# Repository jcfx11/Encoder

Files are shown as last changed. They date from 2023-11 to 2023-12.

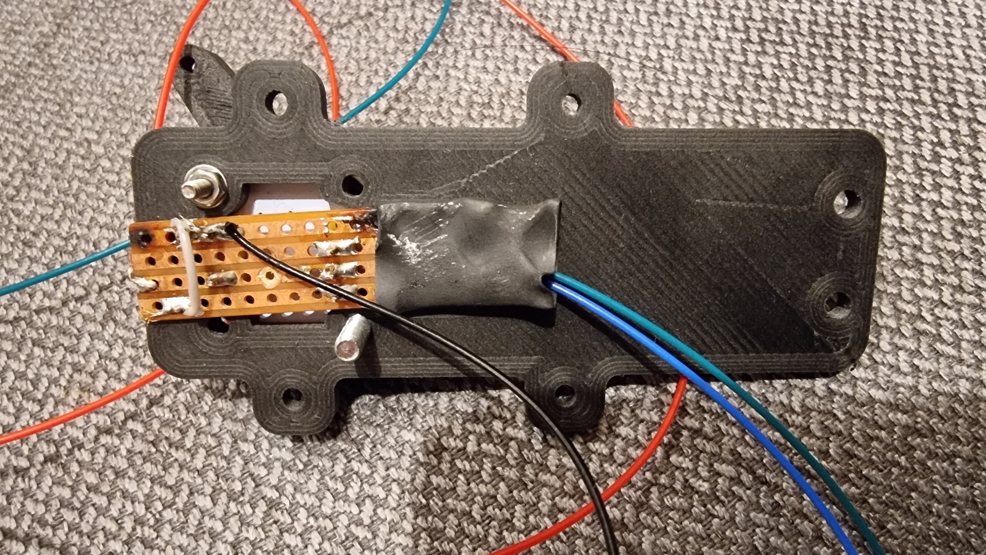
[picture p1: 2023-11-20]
Veroboard sensor wiring.jpg

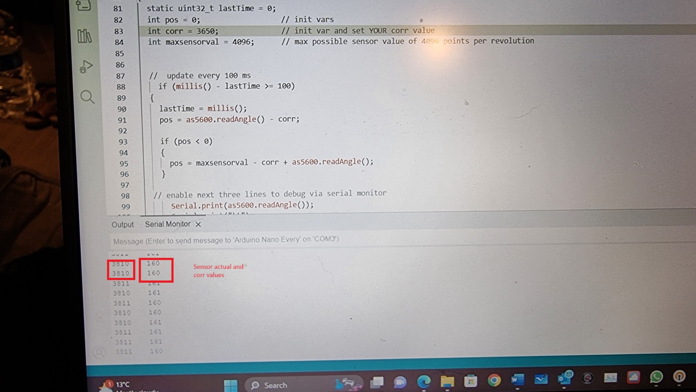
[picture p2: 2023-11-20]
use of calibrate sketch.jpg

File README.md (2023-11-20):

A very simple use of an AS5600 absolute encoder to read an angle and translate that angle to a flap setting displayed on a small oled display. Builds on the work of Scott and Rob Tillart.
Due to the simplicity of the project, ie, no added pusbuttons to set or increment positions, the code is very simple, but does require some ability to change the code where specified to suit your particular installation. I'm using Arduino IDE v2.x

Hardware - Arduino Uno or Nano Every. This code has been tested on both and works. The solution could be ported to any microprocessor that has an I2C bus and provides 3.3V and 5V for the sensor and Oled displays.

AS5600 3.3V absolute encoder, 1.3 inch 5V Mono OLED display from Ebay or similar, 3d printed parts, piece of veroboard, and a "shield" for your microprocessor to enable easy board connections.

Many examples of AS5600 and Oled on Youtube

Needs hands on coding to calibrate and tailor the angles read to the display

The two sensor arms are examples, I expect you will need to tailor the length, for example, to suit your particular installation.
https://www.tinkercad.com/things/aveWrb0Cxmn-flap-sensor-lever

V 1 is complete, ideally V2 will use interupt handling to read the sensor rather than the timer in use now.

Demo of finished article - https://www.youtube.com/shorts/X8wPW7MDXF8

Please excuse my wonky soldering and photos, I'm on holiday.

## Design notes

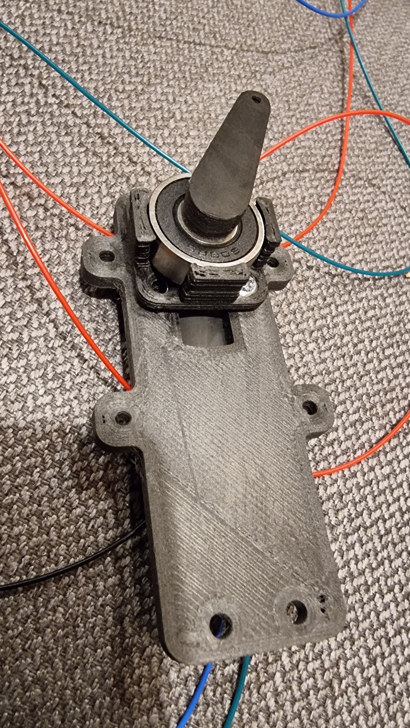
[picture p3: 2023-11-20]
Completed sensor example.jpg

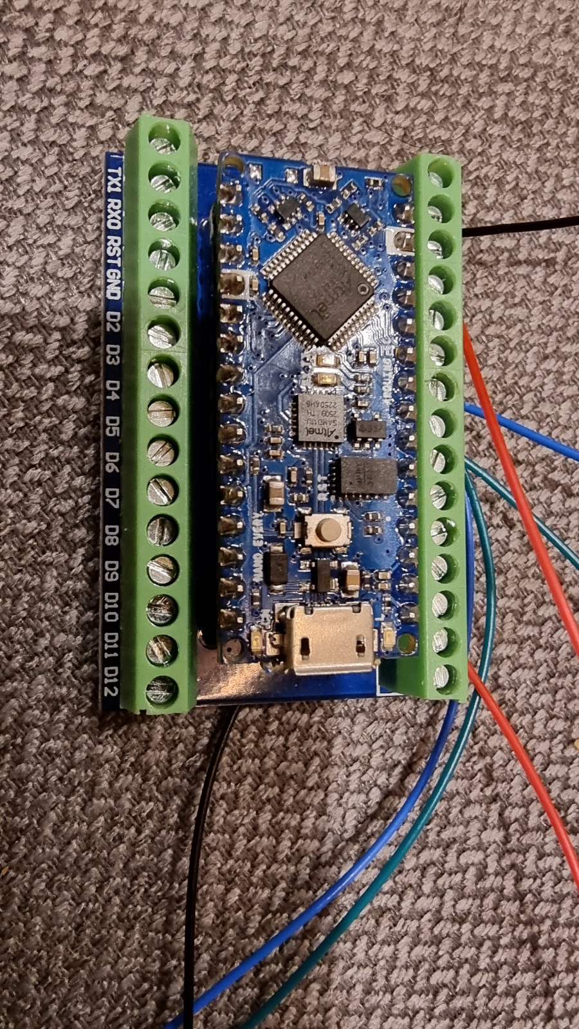
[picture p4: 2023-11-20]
Nano in sheild board.jpg

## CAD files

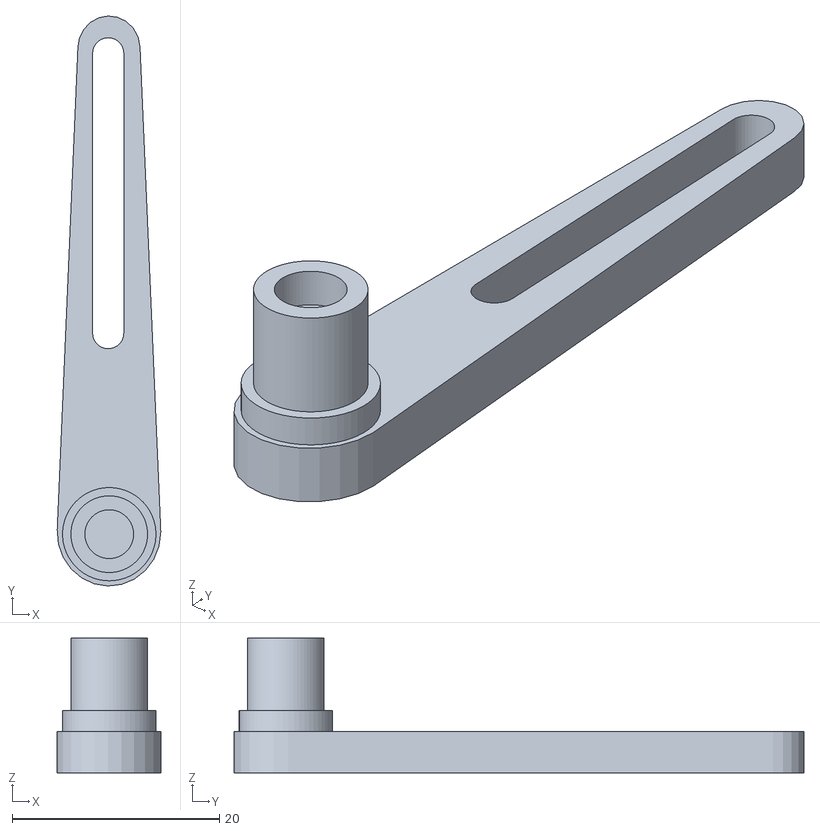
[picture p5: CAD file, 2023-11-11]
Flap sensor arm with slot - Final.stl
9.99 x 55.0 x 13.0

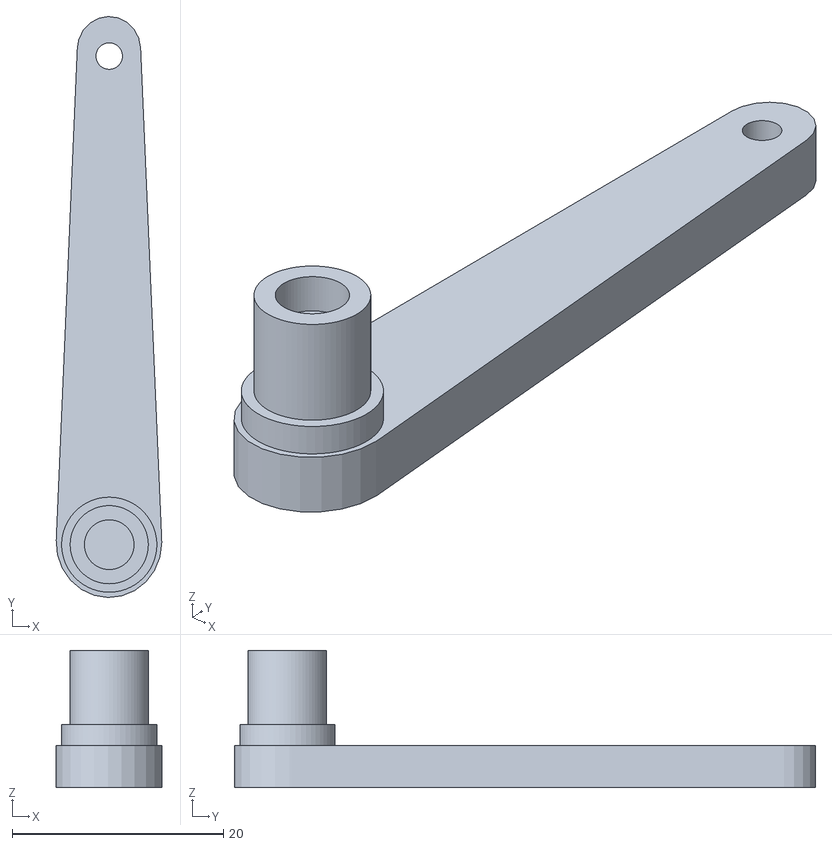
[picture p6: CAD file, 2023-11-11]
Flap sensor arm with hole - Final.stl
9.99 x 55.0 x 13.0

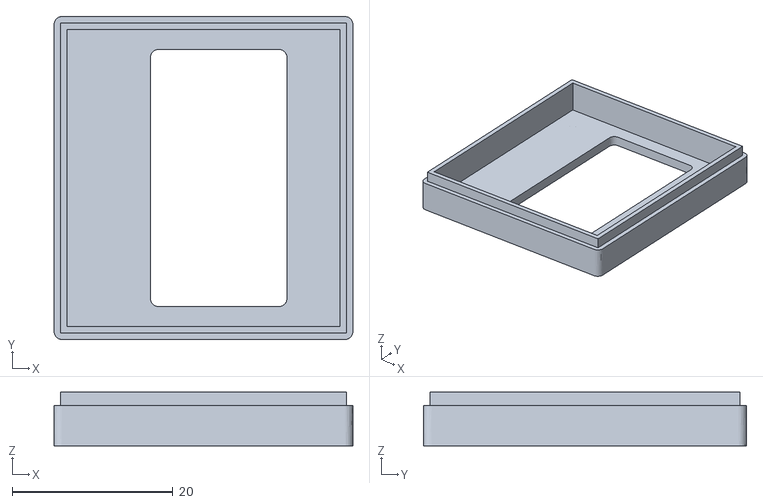
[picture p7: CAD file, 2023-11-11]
1.3 oled case front - Final.stl
37.2 x 40.2 x 6.70

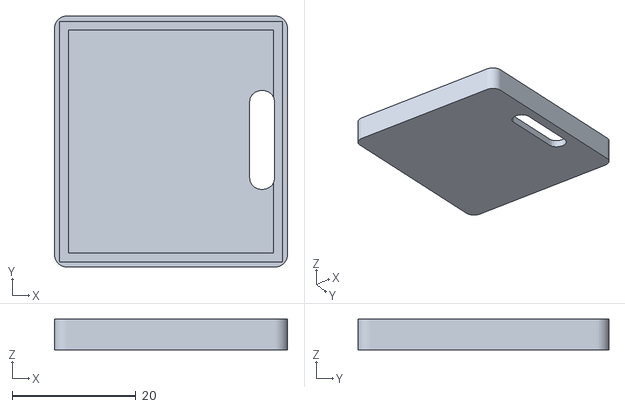
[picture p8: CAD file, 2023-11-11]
1.3 oled case rear - Final.stl
37.6 x 40.5 x 5.00

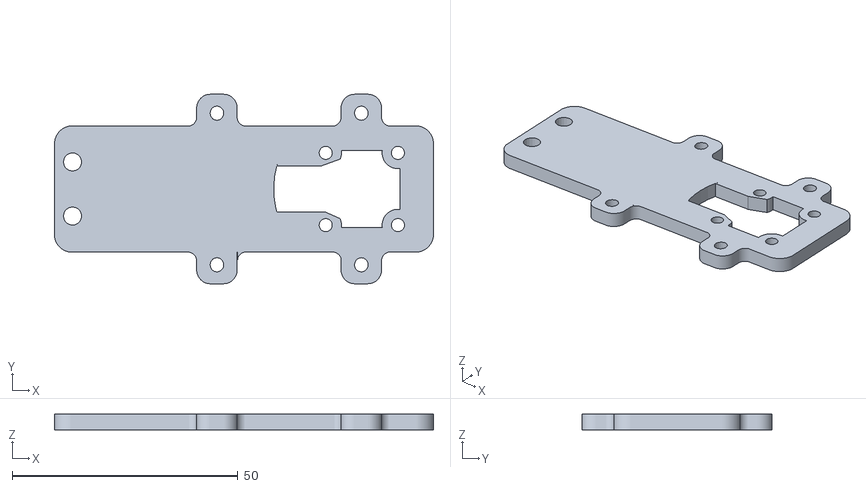
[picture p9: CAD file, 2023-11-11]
Flap sensor mount plate - Final.stl
84.0 x 42.0 x 3.50

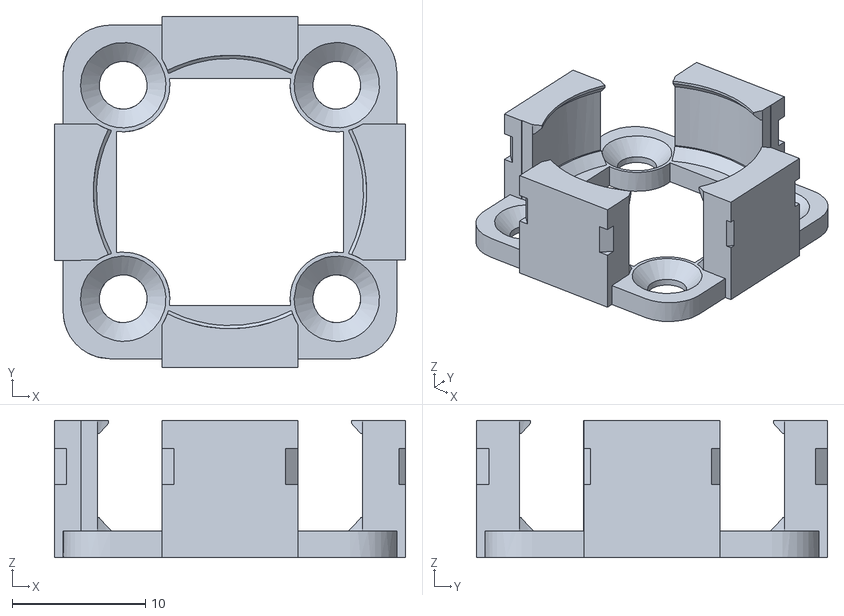
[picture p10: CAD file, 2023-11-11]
AS5600 and 608 bearing mount - Final.stl
26.3 x 26.3 x 10.3

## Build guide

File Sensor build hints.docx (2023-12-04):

# Build hints

Firstly, note that the components are frangible, any resistance should be overcome with a slightly increased force. Do not over engineer a really strong solution !

Acquire the various hardware components, example sources given at end of doc

Print the components and make sure they fit, your printer may have a different tolerance to mine.

Print at 0.1 or 0.15 mm layer height, use 3 or 4 walls, use 20% or 25% infill. Adjust settings as appropriate. Use something with a higher heat resistance than PLA if you live in a warm country

Display case and Oled display – use hot glue or double sided sticky foam pad to hold the Oled to the front case. Use some medium viscosity superglue to join the case halves

Use a tie wrap around the bearing holder to fix the bearing in place

Use a viscous superglue to mount the magnet to the flap arm

Soldering – you can solder directly to the Oled and AS5600 pins. Or you can use some Veroboard to make life easier, or you can make up some 2.54mm Pitch 4 Pin JST SM Connector Dupont Female Pin Headers

Don’t solder directly to the Nano, get a screw terminal shield device to make life easier..

The sensor (AS5600) should rotate clockwise going from Land flap to Speed flap, ie, the sensor value increases as the arm rotates.

Use 4 core shielded cabling, very little current is transmitted.

Keep the Nano behind the panel for ease of access and programming

Add split ferrite cores to cabling in and out of the Nano

Pick a 3d print case for the Nano from Tinkercad or Thingiverse to suit your needs

Read these installation examples here (https://gliding.lxnav.com/wp-content/uploads/manuals/lxFlapsManualEnglishVer0150rev10.pdf) pick a method suitable for your own installation

# Order of build/install

- Print parts
- Build sensor board, bearing mount and arm
- Decide cable routing in order to avoid any control runs
- Test sensor on bench with calibrate.ino, see values alter in the Arduino IDE serial monitor pane
- Install sensor board into glider, do NOT connect the sensor arm directly to the flap handle, always attach to the drive pushrod of the flap cone/bucket
- Run Calibrate, decide if corr value is needed. CORR only necessary IF the readangle passes through zero as flaps move from Land to Speed
- Use table to record your flap POS values
- Calculate the minus and plus fudge factor
- Add values – corr and plus/minus to the Flaps.ino
- Compile and send to your nano
- Attach the display if not already done and test that Flap position display matches reality, if not debug your corr and plus/minus numbers

# Power the board

If you have a good low noise USB power in the panel then use that, otherwise use the 12v glider battery. The Nano will stepdown and still provide 3.3 and 5v.

Don’t power with any more than 12v as the Nano will need to dissipate more heat

# Microprocessor type

Uno should work, all testing done on Nano Every

Any micro that is supported by Arduino IDE and has 3.3v, 5v and an I2C interface should be a viable target

# Display

The Oled 128x64 is the target of this design and all of the case components, however a 128x32 display can be used provided it has I2C capability. In reality any display type could be used but stick to I2C interfaces. The I2C interface is very easy to wire up and to program.

# Components

Oled (https://www.amazon.co.uk/dp/B074N9VLZX?ref=ppx_yo2ov_dt_b_product_details&th=1)

AS5600 (https://www.amazon.co.uk/dp/B09GLPV6WB?psc=1&ref=ppx_yo2ov_dt_b_product_details)

Nano shield (https://www.ebay.co.uk/itm/155756136480?var=456134906693)

Nano every with headers (https://cpc.farnell.com/arduino/abx00033/nano-every-w-header-development/dp/SC18536?st=nano%20every)

Arduino IDE (https://docs.arduino.cc/software/ide-v2)

Radio control pushrods could be used to connect (https://www.nexusmodels.co.uk/aircraft-accessories/model-hardware/linkages-push-rods.html)

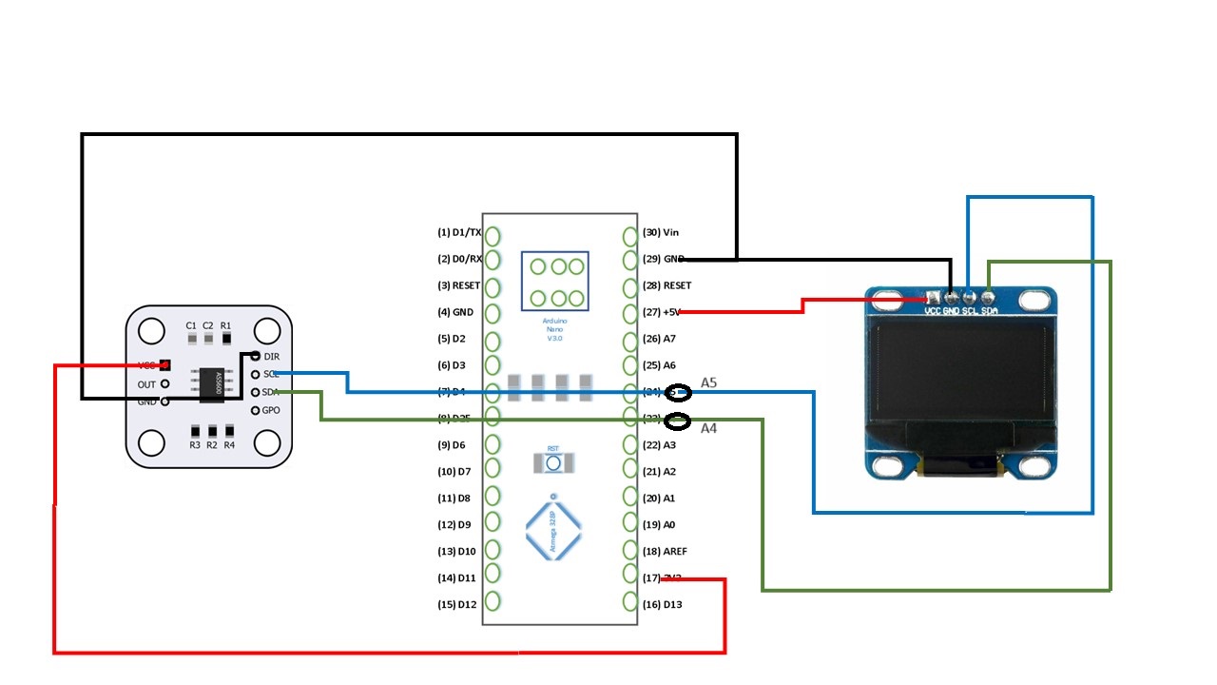
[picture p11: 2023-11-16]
Flaps wiring.jpg

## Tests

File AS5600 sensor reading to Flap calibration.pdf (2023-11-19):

## AS5600 sensor reading to Flap calibration

Having assembled the sensor and installed it in your glider/plane, you will need to record the sensor angular output (0 to 4096) for each of the flap posions you wish to display. The following table is for an ASG29, create a similar table for your installaon.

Lower and upper limits are a fudge factor due to the highly accurate sensor output. The sensor will register 0.1 degree increments, therefore we add a value range to the actual reading to ensure that the flap seng is displayed even when any slack or looseness is present in the installaon.

Having created this table, the values are inserted into the Flaps Arduino code prior to compilaon and upload to the Nano. Refer to the code block example below, this code block is repeated for each flap seng you require.

If the values in the table do NOT wrap round, ie, all values increment and do not cross the 4096 threshold you will not need to use the corr value, set it to zero 0 in the flaps sketch.

If the value does cross the 4096 threshold and wraps round as the example table shows then we will need to use the corr value. Aim for a Land flap value of 100, to calculate the corr value use this;

Corr value = actual reading – 100, which comes to 3650 with a lile rounding. Change the corr value in flaps as shown here

void loop()
{
static uint32_t lastTime = 0; // loop timer
int pos = 0; | // init vars
int corr = 3650; | // init var set corr value
int maxsensorval = 4096; | // max possible sensor value of 4096 points
per revolution

## Actual sensor values as installed – calibrate sketch

Flap posion
Display text

Actual

Land | 3756
Flap 6 | 100
Flap 5 | 400
Flap 4 | 600
Flap 3 | 800
Flap 2 | 900
Flap 1 | 1000

## Re run Calibrate with corr value and calculate the Lower and Upper limits

Flap posion
Display text

Lower limit
Calculated

Pos value aer corr
applied Value

Upper limit
Calculated
Land | 50 | 100 | 150
Flap 6 | 250 | 300 | 350
Flap 5 | 450 | 500 | 550
Flap 4 | 650 | 700 | 750
Flap 3 | 850 | 900 | 950
Flap 2 | 1050 | 1100 | 1150
Flap 1 | 1250 | 1300 | 1350

* Upper limit will not exceed 4096 due to wrapping, sensor reads from 0 to 4096 and then resets to counng from zero. Numbers above are just examples, yours will be different.

Use +- 50 as upper limits and change vales in the code block for each flap seng. +- 50 is an example, yours may need different ranges set.
Code block example

This block shows the settings necessary to show “LAND” on the display

if (pos > 50 && pos < 150) // land flap

{
display.clearDisplay();
display.setTextSize(2);
display.setTextColor(SH110X_WHITE); display.setCursor(0, 50);
display.println("Land"); // Oled text display display.display();

}

## Use of calibrate sketch

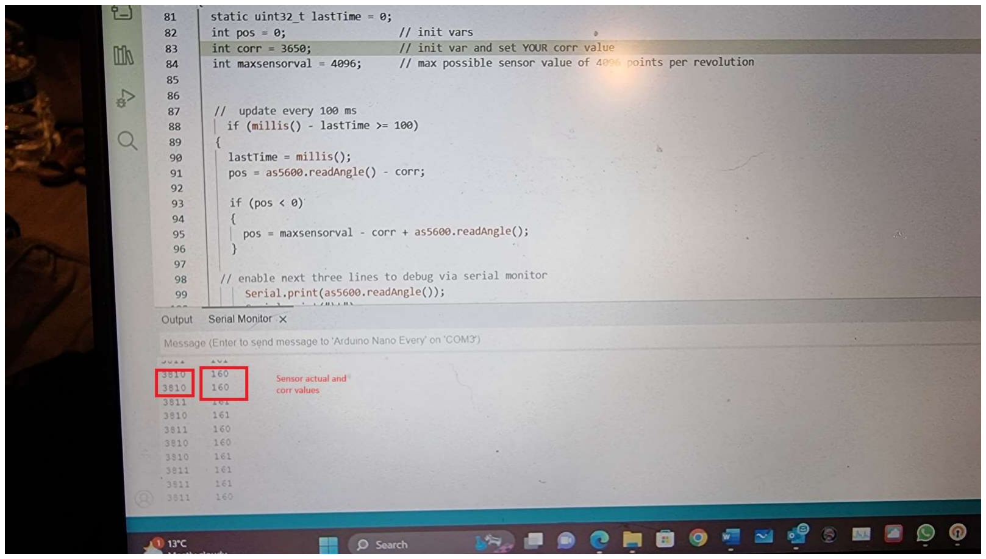
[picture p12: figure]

## Zeroing the AS5600 without use of corr

The sensor will read some random value, ie, not zero when installed. It is very difficult to overcome this BUT it can be done. Please use Rob’s code and instrucons found here

AS5600/examples/AS5600_burn_zpos at master · RobTillaart/AS5600 (github.com)

Note this code is destrucve and can only be run 3 mes on a sensor, use at your own risk !

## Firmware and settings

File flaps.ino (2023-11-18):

//
//    FILE: Flap sensor and display.ino
//  AUTHOR: John Ferguson building on work of Rob Tillaart, x and y
// PURPOSE: Glider flaps encoder sensor and flap position display
//    DATE: 2023-Nov
// AS5600 lib - https://github.com/RobTillaart/AS5600
// Adafruit lib SH110X

/* Parts list

AS5600 encoder          - https://www.amazon.co.uk/dp/B09GLPV6WB?psc=1&ref=ppx_yo2ov_dt_b_product_details
Oled 128x64             - https://www.amazon.co.uk/gp/product/B074N9VLZX/ref=ppx_yo_dt_b_search_asin_title?ie=UTF8&th=1
Bearing                 - generic 608 roller skate bearing, ebay or amazon
3d print parts bearing  - baseplate and bearing mount from tinkercad 
                          https://www.tinkercad.com/things/8eYcTnPwoCL-as5600-and-608-bearing-mount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
                          https://www.tinkercad.com/things/kjFzeW6U8p8-flap-sensor-mount-plate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
Lever arm here          - https://www.tinkercad.com/things/aveWrb0Cxmn-flap-sensor-lever/edit copy and remix for your own purposes
M2.5 nuts and bolts
Veroboard              - ebay or amazon
4 core and shield cable, say 4 m should do

*/

/* AS5600 includes */
#include "AS5600.h"
#include "Wire.h"
AS5600 as5600;   //  use default Wire

/* 128 x 64 Oled includes */

#include <Adafruit_GFX.h>
#include <Adafruit_SH110X.h>
#include <Fonts/FreeSansBold12pt7b.h>

/* Uncomment the initialize the I2C address , uncomment only one, If you get a totally blank screen try the other*/
#define i2c_Address 0x3c //initialize with the I2C addr 0x3C Typically eBay OLED's
//#define i2c_Address 0x3d //initialize with the I2C addr 0x3D Typically Adafruit OLED's

#define SCREEN_WIDTH 128 // OLED display width, in pixels
#define SCREEN_HEIGHT 64 // OLED display height, in pixels
#define OLED_RESET -1   //   QT-PY / XIAO
Adafruit_SH1106G display = Adafruit_SH1106G(SCREEN_WIDTH, SCREEN_HEIGHT, &Wire, OLED_RESET);

/* END of 128 x 64 Oled includes */

void setup()
{
 
  as5600.begin(4);  //  set direction pin.
  as5600.setDirection(AS5600_CLOCK_WISE);  // default, just be explicit.

  delay(250); // wait for the OLED to power up
  display.begin(i2c_Address, true); // Address 0x3C default
 //display.setContrast (0); // dim display, doesn't seem to do anything
 
  display.display();
  delay(250);

  // Clear the buffer.
  display.clearDisplay();
  display.setFont(&FreeSansBold12pt7b); // set your favorite font and size - you will need to alter x and y pos dependent upon font
  //display.setFont(&FreeSans9pt7b);    // other example font
}

void loop()
{
  static uint32_t lastTime = 0; // loop timer
  int pos = 0;                  // init vars
  int corr = 3650;              // init vars
  int maxsensorval = 4096;      // max possible sensor value of 4096 points per revolution

  //  read the sensor value every 100 ms
    if (millis() - lastTime >= 100)
  {
    lastTime = millis();

    // Code block to set the random angle of the encoder to a sensible value for the LAND FLAP position, encode MUST rotate clockwise going from LAND to Speed flaps
    // corr may be left at zero if the "random" position of the sensor reads a sensible low value at LAND FLAP, eg, the range of the sensor must
    // not exceed 4096 and wrap round to zero going from LAND to Speed

    pos = as5600.readAngle() - corr;
    if (pos < 0)
    {
      pos = maxsensorval - corr + as5600.readAngle();
    }

  // clear the display ready for next label
    display.display();
    display.clearDisplay();

    // put the encoder values and labels here - Schleicher in this case - labels are Land, 6, 5, 4, 3, 2, 1
    // Schempp labels are; Land, +2, +1, 0, -1, -2 (best guess)
    // read angle goes 0 to 4096 then resets to 0, cumulative angle keeps incrementing and does not wrap round hence maxsensor val, pos and corr use
    // Example values are embedded below to show how a range of value is set including a small fudge factor to cope with any jitter or vibration in the sensor

    if (pos > 0 && pos  < 200) // land flap
    
    {
        display.clearDisplay();
        display.setTextSize(2);
        display.setTextColor(SH110X_WHITE);
        display.setCursor(0, 50);
        display.println("Land"); // Oled text display
        display.display();
       
    }
 
    if (pos > 200 && pos < 400) // Flap 6
    {
        display.clearDisplay();
        display.setTextSize(2);
        display.setTextColor(SH110X_WHITE);
        display.setCursor(0, 50);
        display.println(" FL 6"); // Oled text display
        display.display();
       
    }
 
    if (pos > 400 && pos < 600) // Flap 5
    {
        display.setTextSize(2);
        display.setTextColor(SH110X_WHITE);
        display.setCursor(0, 50);
        display.println(" FL 5"); // Oled text display
        display.display();
       
    }
 
    if (pos  > 600 && pos < 800) // Flap 4
    {
        display.setTextSize(2);
        display.setTextColor(SH110X_WHITE);
        display.setCursor(0, 50);
        display.println(" FL 4"); // Oled text display
        display.display();
       
    }

    if (pos > 800 && pos < 1000) // Flap 3
    {
        display.setTextSize(2);
        display.setTextColor(SH110X_WHITE);
        display.setCursor(0, 50);
        display.println(" FL 3"); // Oled text display
        display.display();
       
    }

    if (pos > 1000 && pos < 1200) // Flap 2
    {
        display.setTextSize(2);
        display.setTextColor(SH110X_WHITE);
        display.setCursor(0, 50);
        display.println(" FL 2"); // Oled text display
        display.display();
       
    }

    if (pos > 1200 && pos < 1400) // Flap 1
    {
        display.setTextSize(2);
        display.setTextColor(SH110X_WHITE);
        display.setCursor(0, 50);
        display.println(" FL 1"); // Oled text display
        display.display();
       
    }

    
  }



}


// -- END OF FILE --

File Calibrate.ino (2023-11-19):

//
//    FILE: Calibrate code
//  AUTHOR: John Ferguson building on work of Rob Tillaart, x and y
// PURPOSE: Calibrate installation
//    DATE: 2023-Nov- 17
// AS5600 lib - https://github.com/RobTillaart/AS5600
// Adafruit lib SH110X
// How to use
// Build the sensor and install it in glider
// ensure the sensor rotates clockwise, ie, the number printed in the terminal window increases as you go from land flap to speed flap
// Upload Calibrate sketch with sensor fitted in glider, keep laptop attached to sensor with this code window and the serial monitor window opened, set the baud rate of serial monitor
// to 115200 baud
// Make a note of the position number (serial monitor window) for every flap position
// quit program, open the Word doc
// 


/* AS5600 includes */
#include "AS5600.h"
#include "Wire.h"
AS5600 as5600;   //  use default Wire

/* 128 x 64 Oled includes */

#include <Adafruit_GFX.h>
#include <Adafruit_SH110X.h>
#include <Fonts/FreeSansBold12pt7b.h>

/* Uncomment the initialize the I2C address , uncomment only one, If you get a totally blank screen try the other*/
#define i2c_Address 0x3c //initialize with the I2C addr 0x3C Typically eBay OLED's
//#define i2c_Address 0x3d //initialize with the I2C addr 0x3D Typically Adafruit OLED's

#define SCREEN_WIDTH 128 // OLED display width, in pixels
#define SCREEN_HEIGHT 64 // OLED display height, in pixels
#define OLED_RESET -1   //   QT-PY / XIAO
//#define correction
//static uint32_t correction = 0;
Adafruit_SH1106G display = Adafruit_SH1106G(SCREEN_WIDTH, SCREEN_HEIGHT, &Wire, OLED_RESET);

/* END of 128 x 64 Oled includes */

void setup()
{
  Serial.begin(115200);
  Serial.println(__FILE__);
  Serial.print("AS5600_LIB_VERSION: ");
  Serial.println(AS5600_LIB_VERSION);

  as5600.begin(4);  //  set direction pin.
  as5600.setDirection(AS5600_CLOCK_WISE);  // default, just be explicit.

  Serial.println(as5600.getAddress());

  //  as5600.setAddress(0x40);  // AS5600L only

  int b = as5600.isConnected();
  Serial.print("Encoder connected: ");
  Serial.println(b);

  delay(1000);
/* added 128x64 Oled setup */

   delay(250); // wait for the OLED to power up
  display.begin(i2c_Address, true); // Address 0x3C default
 //display.setContrast (0); // dim display
 
  display.display();
  delay(250);

  // Clear the buffer.
  display.clearDisplay();
  display.setFont(&FreeSansBold12pt7b);
  //display.setFont(&FreeSans9pt7b);
}




void loop()
{
  static uint32_t lastTime = 0;
  int pos = 0;                  // init vars
  int corr = 3650;              // init var and set YOUR corr value
  int maxsensorval = 4096;      // max possible sensor value of 4096 points per revolution


  //  update every 100 ms
    if (millis() - lastTime >= 100)
  {
    lastTime = millis();
    pos = as5600.readAngle() - corr;

    if (pos < 0)
    {
      pos = maxsensorval - corr + as5600.readAngle();
    }

  // enable next three lines to debug via serial monitor
      Serial.print(as5600.readAngle());
      Serial.print("\t");
      Serial.print(pos);

      Serial.println();

    // read angle goes 0 to 4096 then resets to 0
  }

}


// -- END OF FILE --

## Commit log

2023-10-18 Add files via upload
    3d printed parts
    [1.3 oled 128 64 (1).stl, 1.3 oled case back.stl, As5600 bearing mount.stl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]
2023-11-11 Add files via upload
    Print at a high resolution, say 0.1 or 0.15mm layer height, Print with 3 or 4 walls to make the towers as strong/solid as possible. Use 20% infill. Print in a material with high glass transition, ie,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
    [AS5600 and 608 bearing mount.stl]
2023-11-11 Add files via upload
    Final production version
    Print at a high resolution, say 0.1 or 0.15mm layer height, Print with 3 or 4 walls to make the towers as strong/solid as possible. Print 3 or 4 top and bottom layers @ 0.1mm layer height. Use 20% in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
    Print in a material with high glass transition, ie, not plain PLA, I use carbon filled nylon but ABS/PETG or others would be suitable.
    [AS5600 and 608 bearing mount - Final.stl]
2023-11-11 Add files via upload
    Print at a high resolution, say 0.1 or 0.15mm layer height, Print with 3 or 4 walls. Print 3 or 4 top and bottom layers @ 0.1mm layer height. Use 20% infill.
    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
    [Flap sensor mount plate - Final.stl]
2023-11-11 Add files via upload
    Final version
    Print at a high resolution, say 0.1 or 0.15mm layer height, Print with 3 walls. Print 3 or 4 top and bottom layers @ 0.1mm layer height. Use 20% infill.
    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
    [1.3 oled case rear - Final.stl]
2023-11-11 Add files via upload
    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
    [1.3 oled case front - Final.stl]
2023-11-11 Add files via upload
    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
    [Flap sensor arm with hole - Final.stl]
2023-11-16 Add files via upload
    Block wiring diagram
2023-11-16 Add files via upload
    Wiring block diagram, note A5 and A4 are the SCL/SDA targets
2023-11-18 Add files via upload
    The flap sensor code
2023-11-19 Add files via upload
    Calibration of your installation by use of calibrate sketch
2023-11-19 Add files via upload
    Use to setup the sensor and obtain flap position values
